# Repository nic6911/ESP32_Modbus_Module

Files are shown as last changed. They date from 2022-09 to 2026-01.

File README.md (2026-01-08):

# ESP32 Modbus Module

## Overview

The ESP32 Modbus module is designed for integrating Modbus-enabled devices with Home Assistant. It supports various devices including:

- **Nilan Ventilation** (CTS602/602Light and CTS400 with Modbus)
- **Wavin AHC9000** (Floor heating)
- **Wavin Sentio** (Floor heating)
- **EM340** (Electricity meter with Modbus)
- **NIBE F1255** (Heatpump)

The module is flexible and can be adapted for other Modbus applications, although no promises are made for unsupported devices.

[Buy the module here](https://www.ustepper.com/shop/#!/products/esphome-modbus-module)

---

## Disclaimer

**Use at your own risk!** Improper connections could potentially damage hardware. The hardware and software have been tested with the listed devices without issues.

---

## Features

- Modbus communication with popular home automation systems (e.g., **Home Assistant**, **ESPHome**).
- Supports multiple devices (Nilan, Wavin, EM340, NIBE, and more).
- Provides wiring and software guides to get started quickly.

---

## December 2025 - Hardware update !
Please be advised that the hardware have been updated with the major changes that the 2 x optocoupler outputs have been removed (legacy functionality), the 2 x pin rows are gone and the flow-control pin has been rewired to GPIO3. Nothing that impacts or degrades performance !

For the adapted code (adjusted flow-control pin) look here: [rev2](esphome_example_code/rev2)

If you have a rev2 - it'll look like this:

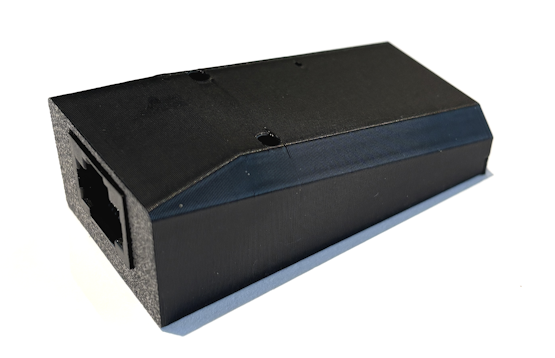
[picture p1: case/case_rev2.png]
Case


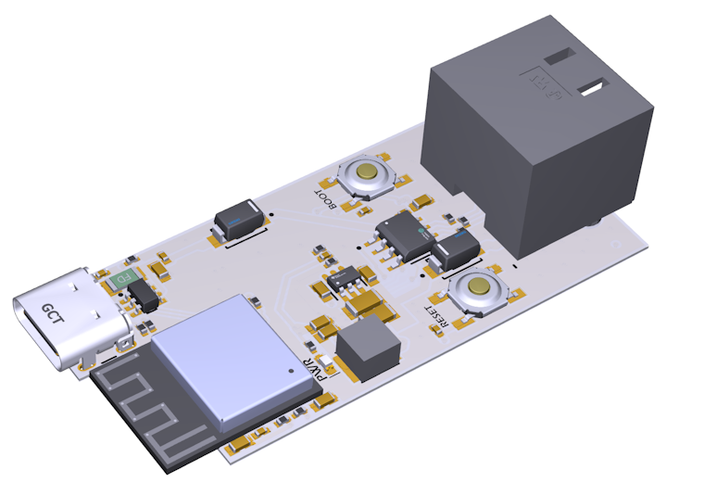
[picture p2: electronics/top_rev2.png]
Topview


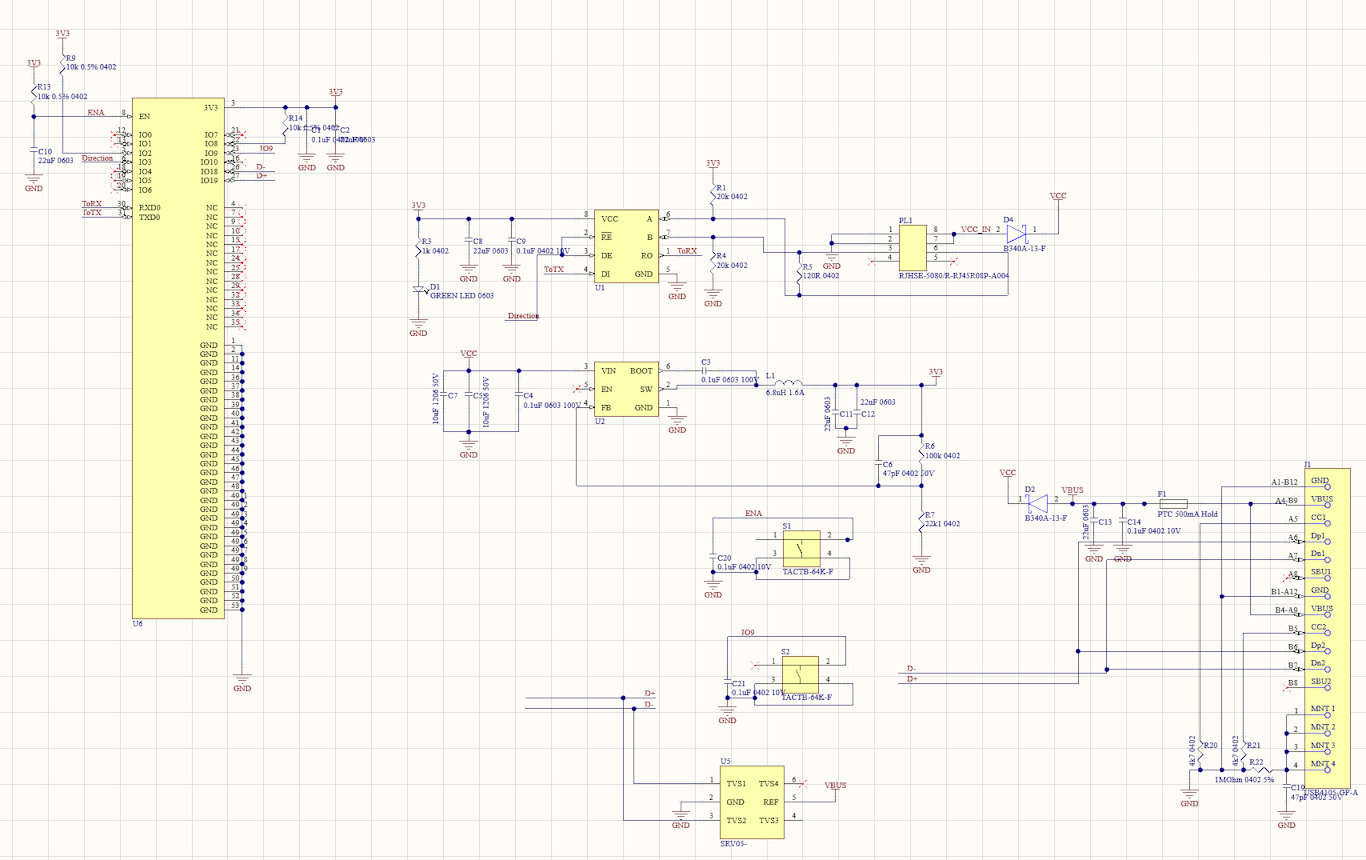
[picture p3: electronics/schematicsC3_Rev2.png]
Schematic


If you have a rev1 - it'll look like this:

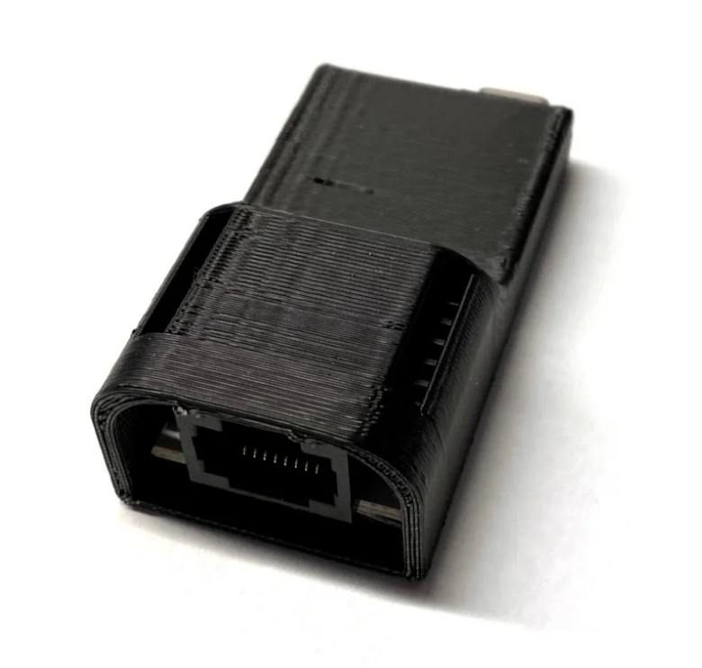
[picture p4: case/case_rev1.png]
Case


And the right code (GPIO10 flow-control pin) is here: [rev1](esphome_example_code/rev1)

## Connecting the Module

### Compatibility Notes

- **RJ45 Interface**: Works specifically with Wavin AHC9000/Sentio.
- Use a **patch cable** to connect the module to the Modbus port for these devices.

### Wiring Information

To connect the module, use an **RJ45B** cable. Cut the cable to expose colored wires, which serve the following functions:

- **A (Modbus+)**
- **B (Modbus-)**
- **GND**
- **+12V (optional)** for power, or use a **USB-C** cable from a charger.

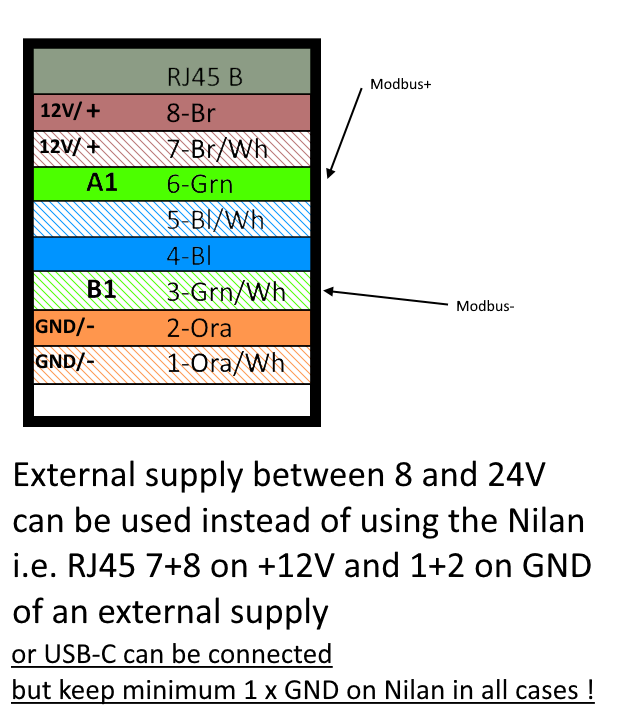
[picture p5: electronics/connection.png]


#### A wiring example on a Nilan CTS602 or CTS602 light is shown here:
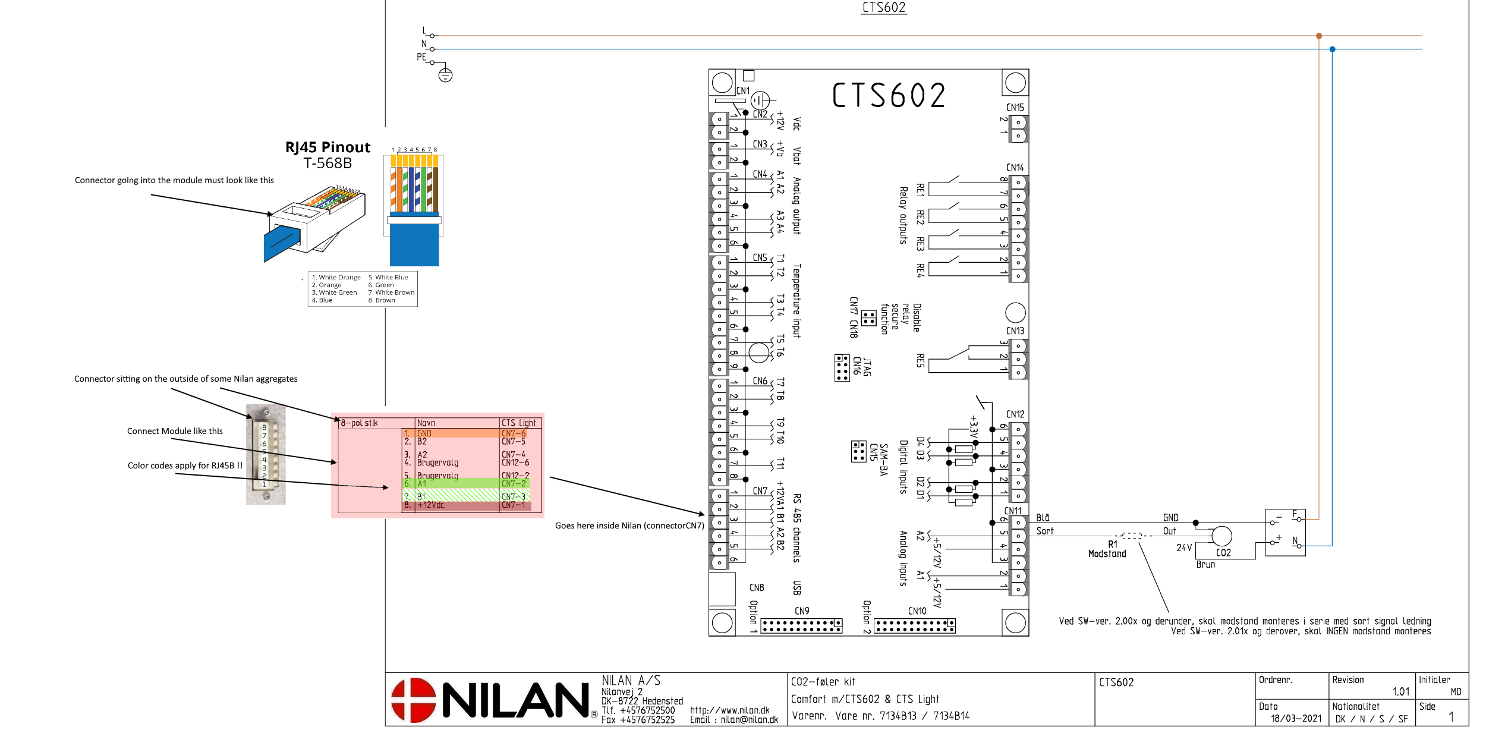
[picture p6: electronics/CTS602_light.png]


#### A wiring example on a Nilan CTS400 is shown here:
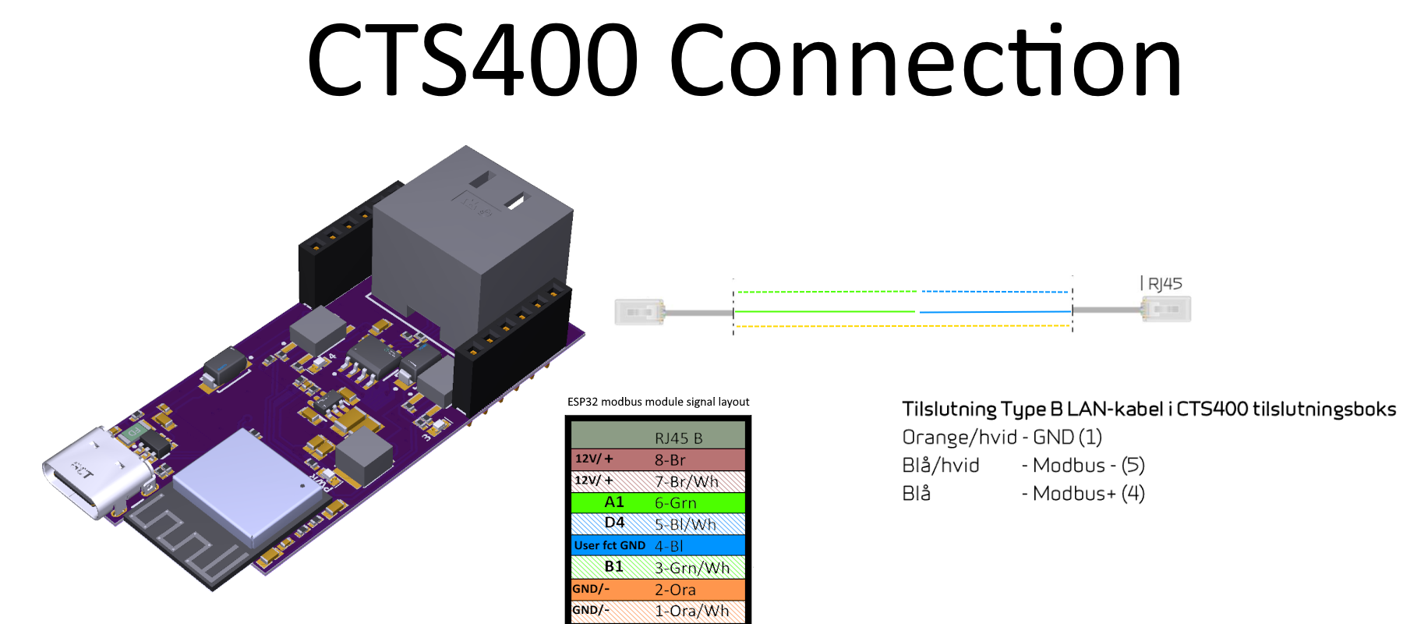
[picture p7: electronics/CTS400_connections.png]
Connections


#### A wiring example on a EM340 modbus power meter is shown here:
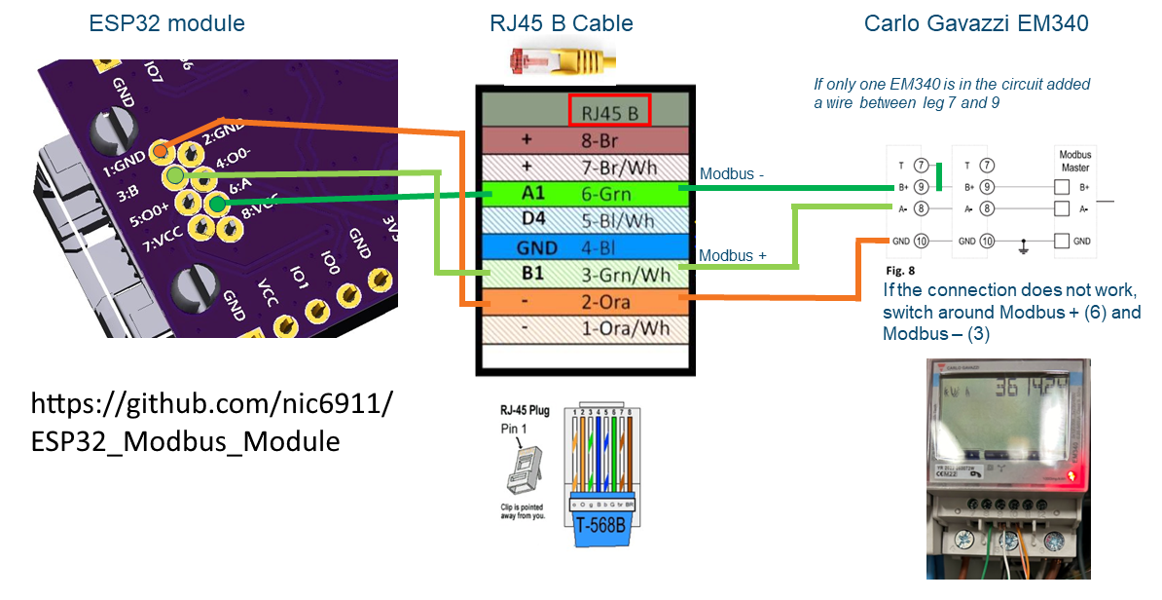
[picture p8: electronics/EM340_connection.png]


#### A Nibe Heat Pump modbus interface is shown here:
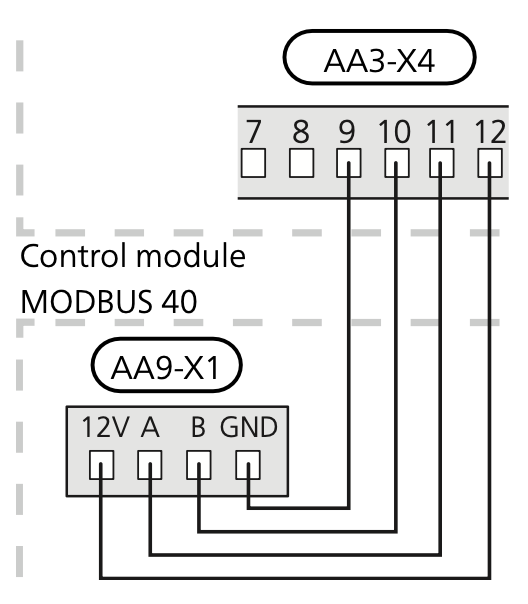
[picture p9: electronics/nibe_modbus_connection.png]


---

## Software Guides

### Installation & Setup

- **Home Assistant & ESPHome**: The module integrates seamlessly with these platforms.
- [Video Guide: USB + WiFi Upload for AHC9000](https://youtu.be/jKOnhiWMCx8)

### Example Code

You can find example code for **Nilan**, **Nibe**, **EM340**, and more in the code folder. A generic setup for **Nilan** is available [here](https://github.com/Jopand/esphome_components/blob/main/README.md).

Example configuration for **Nilan**:

```
esphome:
  name: nilan
esp32:
  board: esp32-c3-devkitm-1
  framework:
    type: arduino

wifi:
  ssid: !secret wifi_ssid
  password: !secret wifi_password
  output_power: "8.5"

uart:
  rx_pin: 20
  tx_pin: 21
  parity: EVEN
  baud_rate: 19200
  id: uart_modbus
  stop_bits: 1
  
modbus:
  id: modbus_id
  flow_control_pin: 10
  uart_id: uart_modbus

```

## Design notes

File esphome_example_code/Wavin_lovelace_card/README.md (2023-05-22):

# Wavin Lovelace Card
Add the .yaml code in a custom card in your lovelace setup. I have a Wavin Sentio system and thus I also have humidity readings.
I have made an automation that syncs all temperatures across the house if I adjust the temperature in the "Sync Temperatur" box. If I want to edit the individual temperatures I simply click on the specific room/zone and the thermostat pops up for me to adjust.

The result with black theme you can see here:
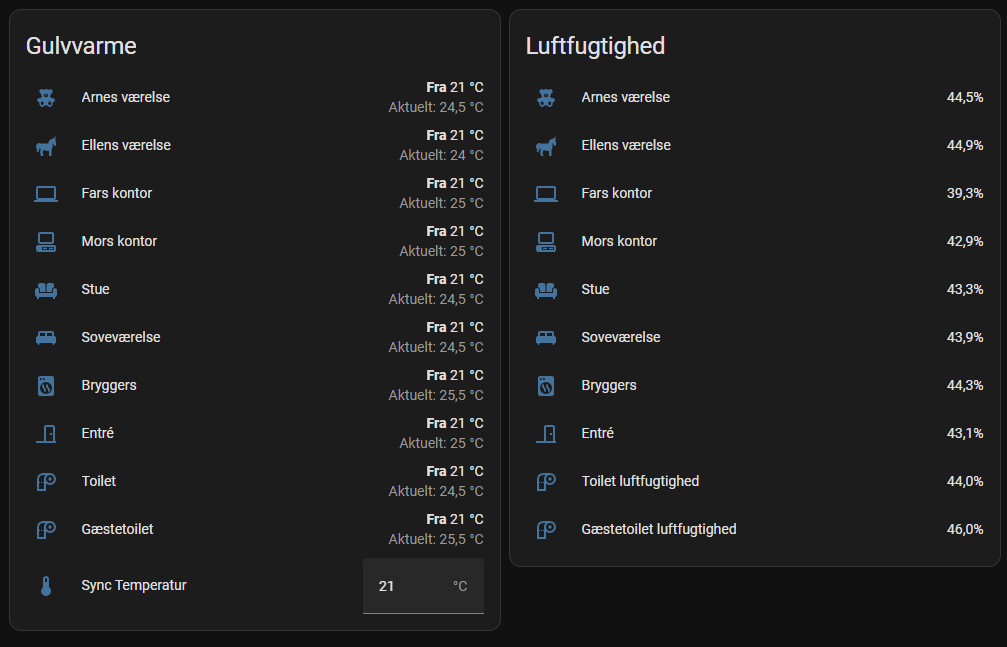
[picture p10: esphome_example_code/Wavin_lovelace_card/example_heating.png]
Example


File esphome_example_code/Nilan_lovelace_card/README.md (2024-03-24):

# Nilan Lovelace Card
Add the .yaml code in a custom card in your lovelace setup. The card has dependencies on HACS custom cards which you will see when trying to implement it. You must then get those dependencies through HACS. 
The `entilation_light.png` and `ventilation.png` image you will have to upload to your Home Assistant folder called "www". 

The result with black theme you can see here:
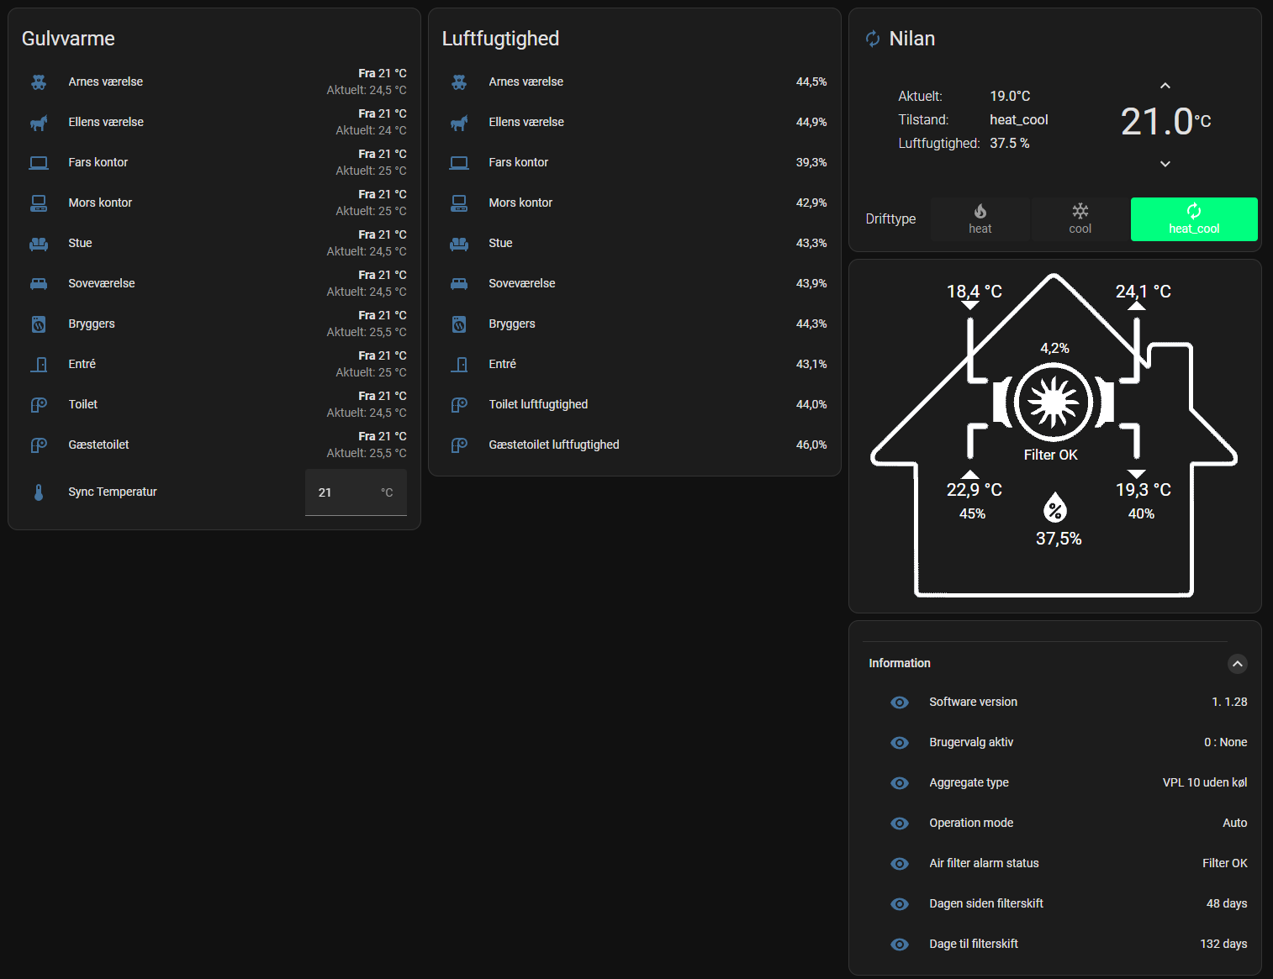
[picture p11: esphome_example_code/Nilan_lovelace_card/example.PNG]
Example


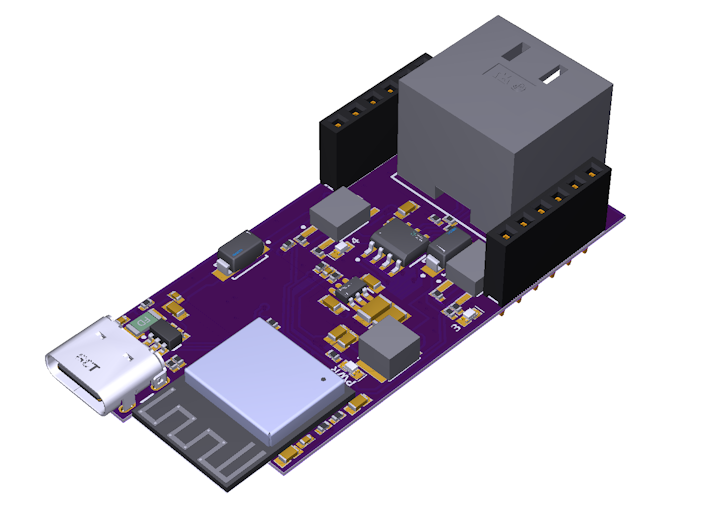
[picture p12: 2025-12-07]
electronics/top.png

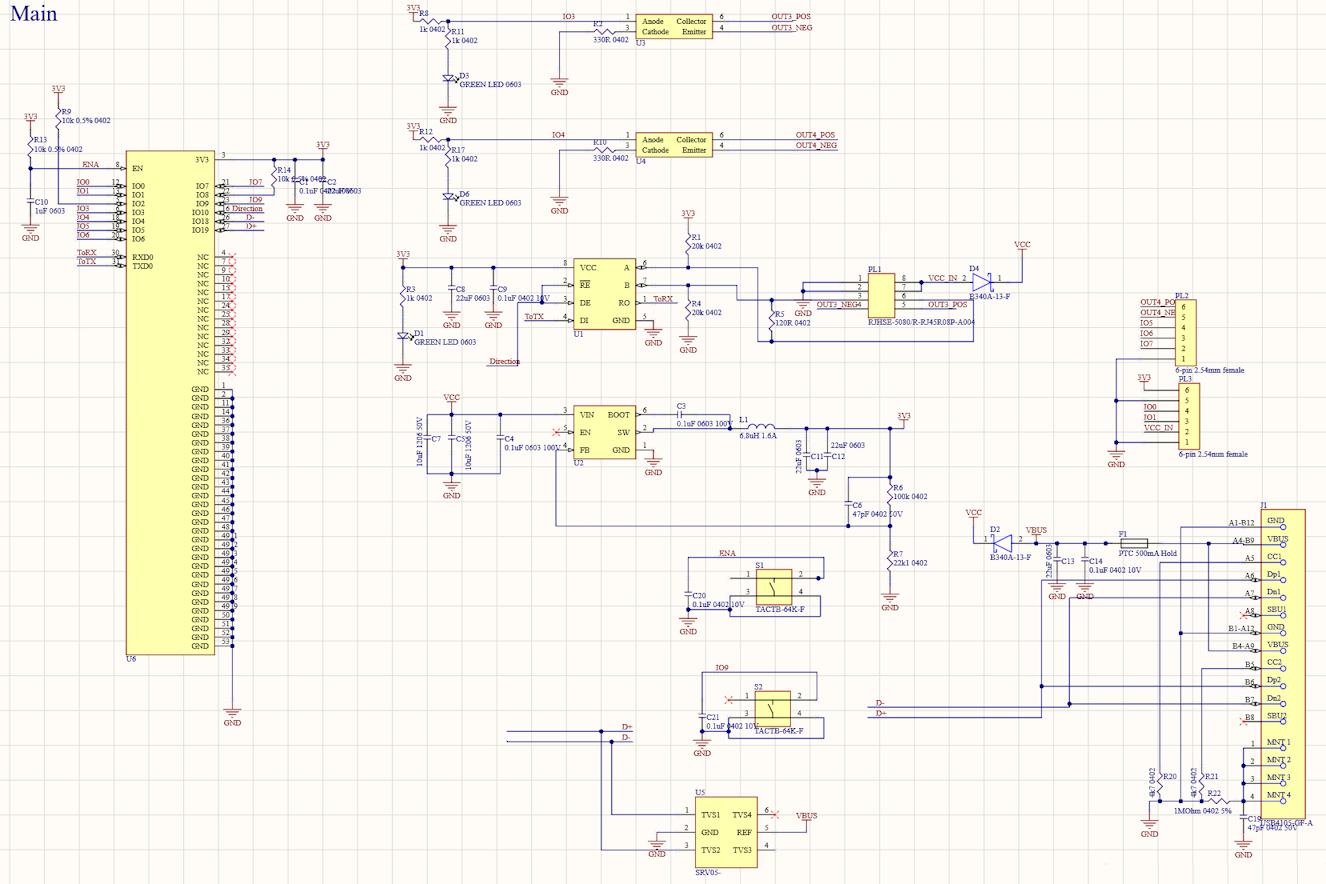
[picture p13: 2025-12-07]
electronics/schematicsC3.png

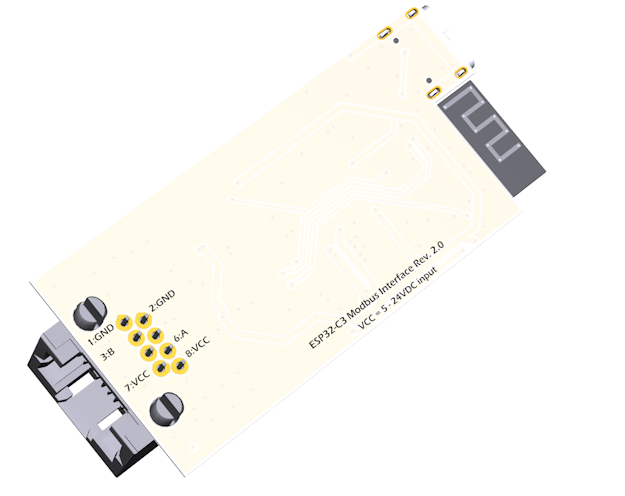
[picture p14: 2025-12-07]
electronics/bottom_rev2.png

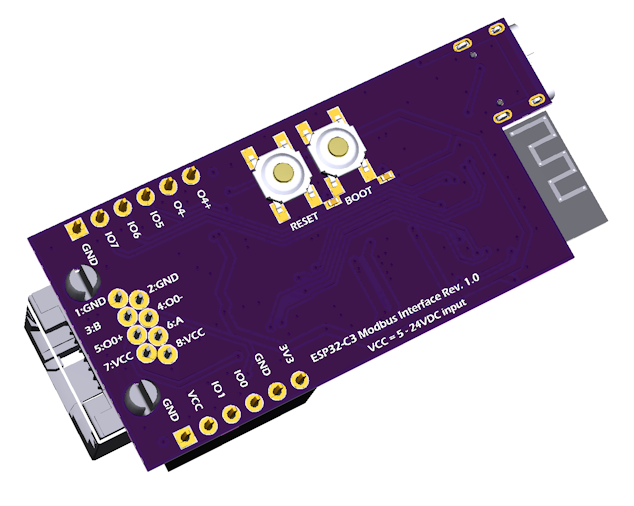
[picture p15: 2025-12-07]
electronics/bottom.png

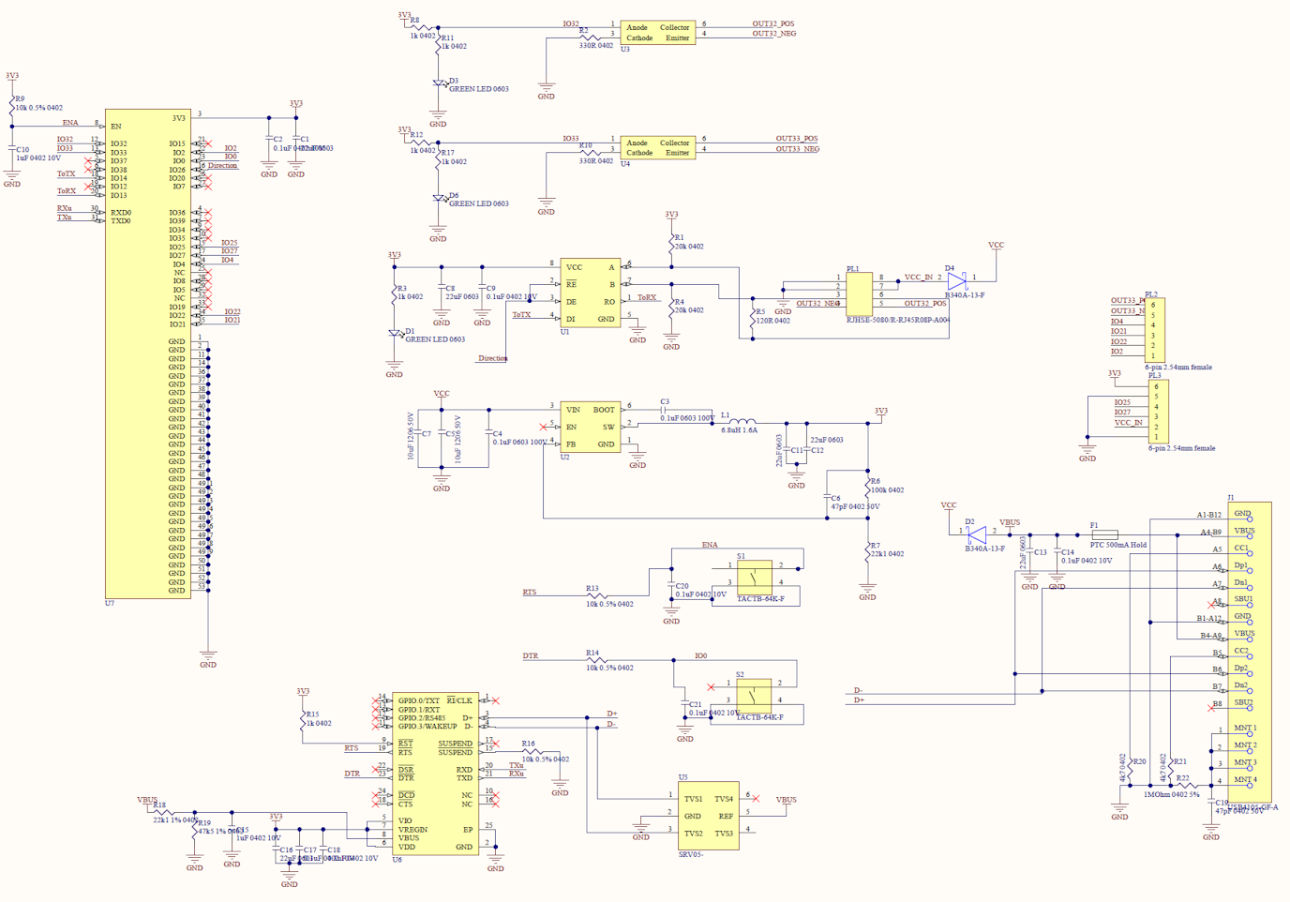
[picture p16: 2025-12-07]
electronics/schematics.png

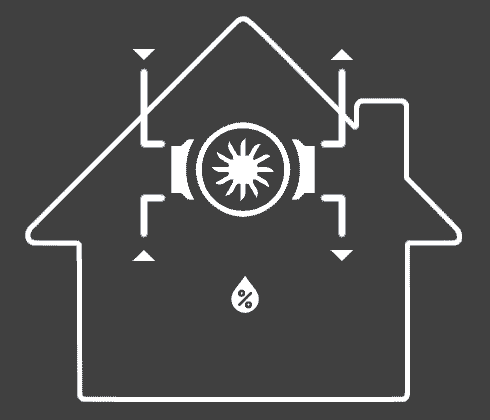
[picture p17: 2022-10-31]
esphome_example_code/Nilan_lovelace_card/ventilation.png

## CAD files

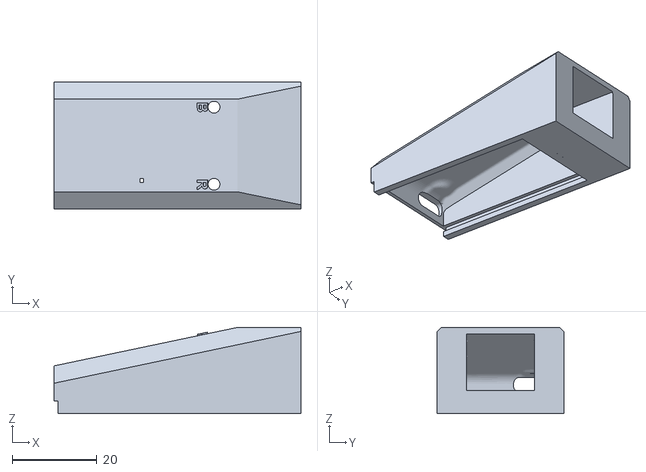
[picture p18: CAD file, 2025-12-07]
case/modbusWavinesp32_rev2_case.stl
58.2 x 29.9 x 20.3

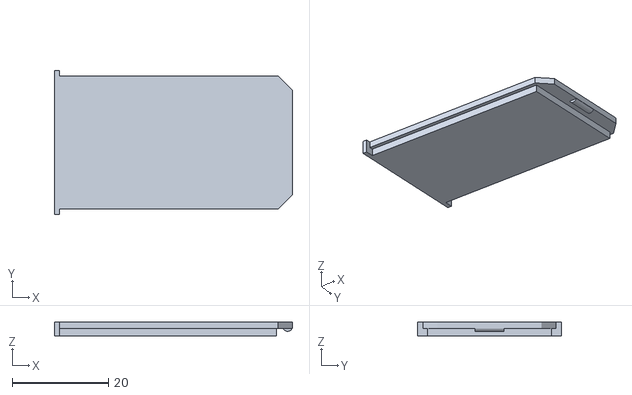
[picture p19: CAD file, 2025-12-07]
case/modbusWavinesp32_rev2_lid.stl
49.5 x 29.9 x 3.00

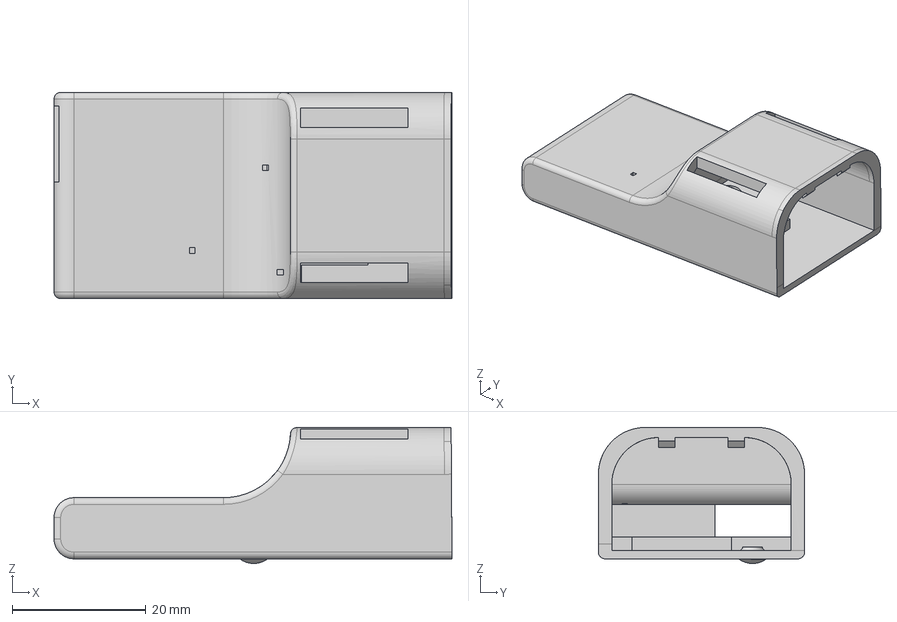
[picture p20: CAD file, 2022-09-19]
case/modbusWavinesp32.step
59.6 x 30.9 x 20.4 mm

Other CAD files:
case/modbusWavinesp32.stl

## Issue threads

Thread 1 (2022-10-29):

Combi 302 Polar missing

JunkStar2k, 2022-10-29:
name: "Aggregate type"
    id: nilan_platform_id
    register_type: holding
    address: 1000

case 35: type_str = "Combi 302 Polar"; break;

nic6911, 2023-11-05:
added

Closed 2023-11-05.

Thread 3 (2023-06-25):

Linked Channels Wavin

joamla96, 2023-06-25:
In my home I have 2 channels that are linked together on the adjuster in the house.

Short of hiding the secondary channel, and making automation that sync's the two, is there a way to combine them in the software as-is?

joamla96, 2023-06-25:
Okay, so, after playing around a little more with it, i may have been to quick to open an issue about it.

When I adjust the temperature on the module in the house, it only changes on one of the channels in Home Assistant, so I presume the head unit is handling the linked channel itself.

uStepper, 2023-07-05:
> Okay, so, after playing around a little more with it, i may have been to quick to open an issue about it.
>
> When I adjust the temperature on the module in the house, it only changes on one of the channels in Home Assistant, so I presume the head unit is handling the linked channel itself.

You are completely right - the head unit is handling this with combining two outputs and one thermostat. So, in case you have two combined channels you’ll just leave out one of them in the esphome code since it has no thermostat.

nic6911, 2023-07-05:
You are completely right - the head unit is handling this with combining two outputs and one thermostat. So, in case you have two combined channels you’ll just leave out one of them in the esphome code since it has no thermostat.

Closed 2023-07-05.

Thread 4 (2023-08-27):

No data

spasserkongen, 2023-08-27:
hvad gør jeg forkert?
jeg har et nilan 300LR, som umiddelbart har stik-forbindelse ligesom på dit readme-billede. Jeg har vedhæftet hvordan jeg har tilslutet ESP-32 modulet til anlægget. Jeg kører 12V udenom da det også drillede.

[logs_nilan_logs(4).txt](https://github.com/nic6911/ESP32_Modus_Module/files/12447694/logs_nilan_logs.4.txt)
![IMG_4053](https://github.com/nic6911/
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
ESP32_Modus_Module/assets/28684092/82012d03-78e1-49b8-861d-9e099c5d8527)

spasserkongen, 2023-08-27:
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

nic6911, 2023-08-27:
Ud fra billedet så har du enten sat orange til 12v (som modulet vil dø af) eller også sidder dine modbus ledninger et forkert sted hverfald hvis jeg kogger her: https://www.nilan.dk/Files/Files/Dansk/Downloads/3.%20Montagevejledninger/M24_Comfort-300LR_DK.pdfBest regards, MogensDen 27. aug. 2023 kl. 11.38 skrev spasserkongen ***@***.***>:

—Reply to this email directly, view it on GitHub, or unsubscribe.You are receiving this because you are subscribed to this thread.Message ID: ***@***.***>

Closed 2023-08-27.

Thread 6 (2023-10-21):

Change filter Alarm

nagydavid, 2023-10-21:
Hi Nico,

I have purchased, from you the ESP32-PICO version. I am using with the Nilan Comfort 300LR and CTS600. Everything is ok, but on the Alarm list in the CTS I am getting and ALARM 91, which is
|  91  |   I OPT IO          | Optionsprint mangler   | Kontakt service   |

and I cannot clear it.

when I press reset alarms, that does nothing. :(

Maybe you have some suggestion?

p.s.: I just would like to you the set/reset filter alarm

nic6911, 2023-11-05:
Have you tried the code from the ESP32-C3? There are some changes there. You of course need to adjust the start of the code to match the PICO instead. Else I would suggest trying out the restructured code from Jopand: https://github.com/Jopand/esphome_components/tree/main

Closed 2023-11-05.

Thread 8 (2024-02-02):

Request for help with wiring

Fredy72, 2024-02-02:
Here it is written about connecting the power supply directly from the CTS602, where, among other things, +12V and GND are output.
> https://github.com/nic6911/ESP32_Modbus_Module/raw/main/electronics/connection.png

Here is a picture of the LILYGO® T-CAN485 wiring in the Nibe heat pump, where PIN9 = GND and PIN12 = +12V (PINs 10 and 11 are Modbus).
> https://github.com/elupus/esphome-nibe/blob/master/examples/lilygo-t-can485.png

I own a LILYGO® T-CAN485 and would like to wiring it up to the CTS602 and powered directly from the CTS602 to the PINs 1,2,3,6.
Pin1 = 12 VDC output
Pin2 = COM1 - RS 485 Data+ (A) - Modbus
Pin3 = COM1 - RS 485 Data- (B) - Modbus
Pin6 = GND

The electrical diagram of the Lily device is as follows.
> https://github.com/Xinyuan-LilyGO/T-CAN485/blob/main/doc/schematic.pdf

I want to ask if it is possible to use the connection in Nilan as pictured with Nibe, i.e. the GND on the RS485 connector (middle PIN) would not be connected (it is written in the first link: "_but keep minimum 1x GND on Nilan in all cases!_")?
Thank you for your answer.

nic6911, 2024-02-02:
Hi,

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

page 4 in the Nilan modbus manual:
https://www.nilan.dk/Files/Files/Dansk/Downloads/7.%20Modbus%20-%20BACnet/2021-01-Modbus_CTS602_w_HMI350T_Modbus.pdf

Fredy72, 2024-02-02:
Thank you for your response.
So are any of these options correct?
In the picture at Nibe it is like this:
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
As an alternative, I thought of this:
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

Fredy72, 2024-02-02:
Another way would be to use the USB output from the CTS602 board to USB LilyGo to power the LilyGo. Would it work?

nic6911, 2024-02-05:
I don't know if the CTS602 has the USB power (or can power back through USB at all) to support that board you have there. With the wiring I can only refer to the doc from Nilan which states that you must use GND. If the GND and RS485GND on the board you have there are tied together I dont know... So the wiring would depend on that.

Closed 2024-02-02.

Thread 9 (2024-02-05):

AHC9000 example code - different versions and missing functionality.

victordk, 2024-02-05:
Hi

Back in 2022 or early 2023 there was a version 2 of the AHC9000 code that integrated more of heinekmadsens esp components.
It had binary sensors for heat output on the individual strings. The current example code does not have these binary sensors - and i am missing them for some automations.

Is there any chance we can have a working code example with those binary sensors?

Hope it makes sense.

nic6911, 2024-02-05:
I have added the V2 example here: esphome_example_code/WavinAHC9000V2_example.yaml

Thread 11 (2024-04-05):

Incorrect data reported from Wavin AHC 9000 with the modbus module.

gudmmk, 2024-04-05:
I'm using your ESP32 Modbus Module that I recently purchased, I hooked it up to a Wavin AHC 9000 ventillation system after I had followed your guide on YouTube on flashing the module for the Wavin AHC 9000.  The module is working great, but there are some discrepancies in the data that's being reported from the ventillation system.

There are 6 channels configured in the Wavin unit.

01: Living Room
03: Master Bedroom
04: Entrance
05: Bedroom 1
06: Bedroom 2
07: Bathroom

The first three issues I encountered are the following:

- Channel 07 reports the temperature as 0 °C. (The thermostat shows the correct temp for the room that it is in)
- Channel 06 is reporting the current temperature for Channel 07. (The thermostat shows the correct temp for the room that it is in)
- Channel 07 reports 0% as the thermostat battery status.

I replaced the batteries in the thermostat for Channel 07 and then I noticed that the battery status for the Channel 07 thermostat is reported as the battery status for the Channel 04 thermostat.

I'm a bit baffled by this, I'm not sure if this might be an issue with the way I did setup/configure the module or if this might be something in the Wavin unit itself.

Any thoughts on this?

[ESPHome_wavin.log](https://github.com/nic6911/ESP32_Modbus_Module/files/14889213/ESPHome_wavin.log)

Here's the YAML that I used to build the firmware and flash the modbus module with.

```
########################################################################################
#                                                                                      #
#      WAVIN AHC-9000 FLOOR HEATING CONTROLLER SOFTWARE FOR HOME ASSISTANT             #
#                                                                                      #
#        Code developed by : Heine Koldbro Madsen and Samuel Sieb 2021                 #
#                                                                                      #
# https://github.com/heinekmadsen/esphome_components/tree/main/components/wavinAhc9000 #
#                                                                                      #
# Hardware by : Mogens Groth Nicolaisen https://github.com/nic6911/Wavin-AHC-9000-mqtt #
#                                                                                      #
########################################################################################

########################################################################################
#                      CONFIGURATION PART OF YOUR CHOICE :)                            #
########################################################################################

substitutions:
  # UNIQUE NAME FOR THE DEVICE
  device: wavin # Case sensitive!!!
  name: "Wavin AHC 9000"  # "Friendly name" - not case sensitive!!!

  # CHANNEL friendly names (If using spaces remember to add ")
  channel_01_friendly_name: "Living Room"
  channel_02_friendly_name: "Channel 02"
  channel_03_friendly_name: "Master Bedroom"
  channel_04_friendly_name: "Entrance"
  channel_05_friendly_name: "Bedroom 1"
  channel_06_friendly_name: "Bedroom 2"
  channel_07_friendly_name: "Bathroom"
  channel_08_friendly_name: "Channel 08"
  channel_09_friendly_name: "Channel 09"
  channel_10_friendly_name: "Channel 10"
  channel_11_friendly_name: "Channel 11"
  channel_12_friendly_name: "Channel 12"
  channel_13_friendly_name: "Channel 13"
  channel_14_friendly_name: "Channel 14"
  channel_15_friendly_name: "Channel 15"
  channel_16_friendly_name: "Channel 16"
  channel_17_friendly_name: "Channel 17"

  # CHANNEL ID´S (ONLY LOWER CASE LETTERS, NO SPACES) used for entity ids
  channel_01_id: channel_01
  channel_02_id: channel_02
  channel_03_id: channel_03
  channel_04_id: channel_04
  channel_05_id: channel_05
  channel_06_id: channel_06
  channel_07_id: channel_07
  channel_08_id: channel_08
  channel_09_id: channel_09
  channel_10_id: channel_10
  channel_11_id: channel_11
  channel_12_id: channel_12
  channel_13_id: channel_13
  channel_14_id: channel_14
  channel_15_id: channel_15
  channel_16_id: channel_16
  channel_17_id: channel_17

 # CHANNEL Alignments (ONLY change if you have offsets in channel vs temperature. Some have reported this if using multiple strings pr. room thermostat)
  channel_01_sensor: "0x00"
  channel_02_sensor: "0x01"
  channel_03_sensor: "0x02"
  channel_04_sensor: "0x03"
  channel_05_sensor: "0x04"
  channel_06_sensor: "0x05"
  channel_07_sensor: "0x06"
  channel_08_sensor: "0x07"
  channel_09_sensor: "0x08"
  channel_10_sensor: "0x09"
  channel_11_sensor: "0x0A"
  channel_12_sensor: "0x0B"
  channel_13_sensor: "0x0C"
  channel_14_sensor: "0x0D"
  channel_15_sensor: "0x0E"
  channel_16_sensor: "0x0F"
  channel_17_sensor: "0x14"

  channel_01: "0x00"
  channel_02: "0x01"
  channel_03: "0x02"
  channel_04: "0x03"
  channel_05: "0x04"
  channel_06: "0x05"
  channel_07: "0x06"
  channel_08: "0x07"
  channel_09: "0x08"
  channel_10: "0x09"
  channel_11: "0x0A"
  channel_12: "0x0B"
  channel_13: "0x0C"
  channel_14: "0x0D"
  channel_15: "0x0E"
  channel_16: "0x0F"
  channel_17: "0x14"

   # UPDATE TIME (GATEWAY)
  update_interval: 60s

  # PIN DEFINITIONS (Should in most cases not be changed)
  rx_pin: '20'
  tx_pin: '21'

  # WiFi settings
  ssid_set: "<redacted>"
  password_set: "<redacted>"

########################################################################################
#                        CODE BELOW SHOULD NOT BE CHANGED                              #
########################################################################################

esphome:
  name: ${device}

esp32:
  board: esp32-c3-devkitm-1
  framework:
    type: arduino

# Enable logging
logger:
  baud_rate: 0

# Enable Home Assistant API
api:

ota:

wifi:
  ssid: ${ssid_set}
  password: ${password_set}

  # Enable fallback hotspot (captive portal) in case wifi connection fails
  ap:
    ssid: "Wavin Fallback Hotspot"
    password: "<redacted>"

captive_portal:

uart:
  - id: uart_${device}
    rx_pin: ${rx_pin}
    tx_pin: ${tx_pin}
    baud_rate: 38400
    stop_bits: 1
    parity: NONE

modbus:
    - id: ${device}_modbus
      uart_id: uart_${device}
      flow_control_pin: 10

modbus_controller:
  id: ${device}_modbus_controller
  address: 1
  modbus_id: wavin_modbus
  update_interval: ${update_interval}

packages:
  remote_package:
    url: https://github.com/nic6911/esphome_components
    ref: more_channels
    files:
      - components/wavinahc9000v2/configs/basic.yaml # REQUIRED FOR WAVIN AHC 9000
      - components/wavinahc9000v2/configs/channel_01.yaml
      #- components/wavinahc9000v2/configs/channel_01_comfort.yaml # Only for channels with thermostat with IR sensor
      - components/wavinahc9000v2/configs/channel_02.yaml
      #- components/wavinahc9000v2/configs/channel_02_comfort.yaml # Only for channels with thermostat with IR sensor
      - components/wavinahc9000v2/configs/channel_03.yaml
      #- components/wavinahc9000v2/configs/channel_03_comfort.yaml # Only for channels with thermostat with IR sensor
      - components/wavinahc9000v2/configs/channel_04.yaml
      #- components/wavinahc9000v2/configs/channel_04_comfort.yaml # Only for channels with thermostat with IR sensor
      - components/wavinahc9000v2/configs/channel_05.yaml
      #- components/wavinahc9000v2/configs/channel_05_comfort.yaml # Only for channels with thermostat with IR sensor
      - components/wavinahc9000v2/configs/channel_06.yaml
      #- components/wavinahc9000v2/configs/channel_06_comfort.yaml # Only for channels with thermostat with IR sensor
      - components/wavinahc9000v2/configs/channel_07.yaml
      #- components/wavinahc9000v2/configs/channel_07_comfort.yaml # Only for channels with thermostat with IR sensor
      - components/wavinahc9000v2/configs/channel_08.yaml
      #- components/wavinahc9000v2/configs/channel_08_comfort.yaml # Only for channels with thermostat with IR sensor
      - components/wavinahc9000v2/configs/channel_09.yaml
      #- components/wavinahc9000v2/configs/channel_09_comfort.yaml # Only for channels with thermostat with IR sensor
      - components/wavinahc9000v2/configs/channel_10.yaml
      #- components/wavinahc9000v2/configs/channel_10_comfort.yaml # Only for channels with thermostat with IR sensor
      - components/wavinahc9000v2/configs/channel_11.yaml
      #- components/wavinahc9000v2/configs/channel_11_comfort.yaml # Only for channels with thermostat with IR sensor
      - components/wavinahc9000v2/configs/channel_12.yaml
      #- components/wavinahc9000v2/configs/channel_12_comfort.yaml # Only for channels with thermostat with IR sensor
      - components/wavinahc9000v2/configs/channel_13.yaml
      #- components/wavinahc9000v2/configs/channel_13_comfort.yaml # Only for channels with thermostat with IR sensor
      - components/wavinahc9000v2/configs/channel_14.yaml
      #- components/wavinahc9000v2/configs/channel_14_comfort.yaml # Only for channels with thermostat with IR sensor
      - components/wavinahc9000v2/configs/channel_15.yaml
      #- components/wavinahc9000v2/configs/channel_15_comfort.yaml # Only for channels with thermostat with IR sensor
      - components/wavinahc9000v2/configs/channel_16.yaml
      #- components/wavinahc9000v2/configs/channel_16_comfort.yaml # Only for channels with thermostat with IR sensor
      - components/wavinahc9000v2/configs/channel_17.yaml
    refresh: 0s
```

nic6911, 2024-04-05:
Hi,

you have most likely two strings on one thermostat - which requires you to edit the offset section so that it does not try to read the channel thermostat that is not there.
 Read more here: https://github.com/heinekmadsen/esphome_components

Closed 2024-04-05.

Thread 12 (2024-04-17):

Couldn't find ID 'wavin_modbus'.

Inrego, 2024-04-17:
I'm trying to install on the unit I purchased. I'm using the yaml from https://github.com/nic6911/ESP32_Modbus_Module/blob/main/esphome_example_code/WavinAHC9000V2_example.yaml but during compile, I get the error `Couldn't find ID 'wavin_modbus'.`

Inrego, 2024-04-17:
Found the bug:

Changed this line:
https://github.com/nic6911/ESP32_Modbus_Module/blob/20d9334d7542a3a562a640915ec5420a52b6e496/esphome_example_code/WavinAHC9000V2_example.yaml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

to this:
`modbus_id: ${device}_modbus`

Closed 2024-04-19.

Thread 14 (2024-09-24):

Wanting to connect to DVI Heat Pump

Inrego, 2024-09-24:
Hi there. I'm already using one of these for my Waving floor heating. It's great!
Now, I'm looking to smartify my heat pump, which is a DVI Heat Pump. They've sent me the modbus specifications.

The connector is a DB-9 port. Do you think it would be so simple, that I can just use a cable like this to connect your device to the serial port?
https://www.proshop.dk/Kabler-diverse/Datalogic-CAB-327-RS232-CABLE-CABL/2348820

Or would I have to cut it and join the individual wires to a specific mapping?

nic6911, 2024-09-24:
Hi,
That really depends on the layout of that cable and the DVI Heat Pump. You can see the layout of my RJ45 connector here on the repo :) It would be a strike of luck if it just matched 1:1 with Wavin I guess...

Inrego, 2024-09-24:
I'm just thinking, that since these kinds of cables do exist, there's probably some standardized mapping between the two connectors. So it might not just be luck. But it sounds like you don't necessarily have any knowledge on the subject, so I'll research some more on my own.

nic6911, 2024-09-24:
Based on my knowledge on Nilan and Wavin (which both can have RJ45 connectors for modbus) I would not expect it to follow any standard. And no, I do not know exactly how that cable you refer to is pinned out and how the DVI unit has it's layout on the DB9 connector :) You'll have to do a little research there on your own :)

Inrego, 2024-09-30:
I found one of these bad boys. It's arriving today. So time to tinker!
https://www.av-cables.dk/d-sub-stik/terminal-block-adapter-sub-d-9-pin-han-til-til-terminal-block.html

Closed 2024-09-24.

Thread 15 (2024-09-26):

Wavin sentio ccu8 no data

tvc-dps, 2024-09-26:
Hello

Using module from https://www.ustepper.com/shop/#!/products/esphome-modbus-module
Physically connected over rj45 to Wavin Sentio CCU-208 port A (1st on the left)
Used template/configuration example at https://github.com/nic6911/ESP32_Modbus_Module/blob/main/esphome_example_code/WavinSentio_example.yaml

No data received.
Below is the log:

```
[10:58:39][D][api.connection:1445]: Home Assistant 2024.9.3 (192.168.100.79): Connected successfully
[10:58:39][C][modbus_controller.sensor:010]: modbus_controller.sensorModbus Controller Sensor 'Living room dugpunkt'
[10:58:39][C][modbus_controller.sensor:010]: modbus_controller.sensor  Device Class: 'humidity'
[10:58:39][C][modbus_controller.sensor:010]: modbus_controller.sensor  State Class: ''
[10:58:39][C][modbus_controller.binary_sensor:009]: Modbus Controller Binary Sensor 'Lav batteri Living room'
[10:58:39][C][sentio.climate:055]: Sentio Climate 'Bathroom LVL2'
[10:58:39][C][sentio.climate:055]: Sentio Climate 'Bathroom LVL1'
[10:58:39][C][sentio.climate:055]: Sentio Climate 'Kitchen'
[10:58:39][C][sentio.climate:055]: Sentio Climate 'Hallway'
[10:58:39][C][sentio.climate:055]: Sentio Climate 'Living room'
[10:58:39][C][modbus_controller:345]: ModbusController:
[10:58:39][C][modbus_controller:346]:   Address: 0x01
[10:58:39][C][modbus_controller:347]:   Max Command Retries: 4
[10:58:39][C][captive_portal:089]: Captive Portal:
[10:58:40][D][modbus_controller:038]: Modbus command to device=1 register=0x78 no response received - removed from send queue
[10:58:40][W][modbus:114]: Modbus CRC Check failed! 71A1!=A2FD
[10:58:40][W][modbus:114]: Modbus CRC Check failed! 7108!=FDA2
[10:58:40][W][modbus:114]: Modbus CRC Check failed! 98B0!=A4FC
[10:58:40][W][modbus:114]: Modbus CRC Check failed! 115A!=FCA4
[10:58:40][W][modbus:114]: Modbus CRC Check failed! 4040!=FFFF
[10:58:40][W][modbus:114]: Modbus CRC Check failed! 4040!=FFA2
[10:58:40][W][modbus:114]: Modbus CRC Check failed! ABB1!=A0FF
[10:58:41][W][modbus:114]: Modbus CRC Check failed! 71A1!=A2FD
[10:58:41][W][modbus:114]: Modbus CRC Check failed! 7108!=FDA2
[10:58:41][D][modbus_controller:038]: Modbus command to device=1 register=0x7A no response received - removed from send queue
[10:58:41][W][modbus:114]: Modbus CRC Check failed! 98B0!=EBFC
[10:58:41][W][modbus:114]: Modbus CRC Check failed! 6331!=FFFF
[10:58:41][W][modbus:114]: Modbus CRC Check failed! 4040!=FFFF
[10:58:41][W][modbus:114]: Modbus CRC Check failed! AA91!=A2FF
[10:58:41][W][modbus:114]: Modbus CRC Check failed! B079!=FFA6
[10:58:42][W][modbus:114]: Modbus CRC Check failed! 71A1!=A2FD
[10:58:42][W][modbus:114]: Modbus CRC Check failed! 7108!=FDA2
[10:58:42][W][modbus:114]: Modbus CRC Check failed! 98B0!=A4FC
[10:58:42][W][modbus:114]: Modbus CRC Check failed! 115A!=FCA4
[10:58:42][W][modbus_controller:182]: Duplicate modbus command found: type=0x3 address=219 count=1
[10:58:42][W][modbus_controller:182]: Duplicate modbus command found: type=0x3 address=220 count=1
[10:58:42][W][modbus_controller:182]: Duplicate modbus command found: type=0x3 address=222 count=1
[10:58:42][W][modbus_controller:182]: Duplicate modbus command found: type=0x3 address=319 count=1
[10:58:42][W][modbus_controller:182]: Duplicate modbus command found: type=0x3 address=320 count=1
[10:58:42][W][modbus_controller:182]: Duplicate modbus command found: type=0x3 address=322 count=1
[10:58:42][W][modbus_controller:182]: Duplicate modbus command found: type=0x3 address=419 count=1
[10:58:42][W][modbus_controller:182]: Duplicate modbus command found: type=0x3 address=420 count=1
[10:58:42][W][modbus_controller:182]: Duplicate modbus command found: type=0x3 address=422 count=1
[10:58:42][W][modbus_controller:182]: Duplicate modbus command found: type=0x3 address=819 count=1
[10:58:42][W][modbus_controller:182]: Duplicate modbus command found: type=0x3 address=820 count=1
[10:58:42][W][modbus_controller:182]: Duplicate modbus command found: type=0x3 address=822 count=1
[10:58:42][W][modbus_controller:182]: Duplicate modbus command found: type=0x4 address=101 count=4
[10:58:42][W][modbus_controller:182]: Duplicate modbus command found: type=0x4 address=106 count=2
[10:58:42][W][modbus_controller:182]: Duplicate modbus command found: type=0x4 address=201 count=4
[10:58:42][W][modbus_controller:182]: Duplicate modbus command found: type=0x4 address=206 count=2
[10:58:42][W][modbus_controller:182]: Duplicate modbus command found: type=0x4 address=301 count=4
[10:58:43][W][modbus:114]: Modbus CRC Check failed! 71A1!=A2FD
[10:58:43][W][modbus:114]: Modbus CRC Check failed! 7108!=FDA2
[10:58:43][W][modbus:114]: Modbus CRC Check failed! 98B0!=A4FC
[10:58:43][W][modbus:114]: Modbus CRC Check failed! 115A!=FCA4
[10:58:43][W][modbus:114]: Modbus CRC Check failed! 4040!=FFFF
[10:58:43][W][modbus:114]: Modbus CRC Check failed! 4040!=FFA2
[10:58:43][W][modbus:114]: Modbus CRC Check failed! ABB1!=A0FF
[10:58:43][W][modbus:114]: Modbus CRC Check failed! 107A!=DFFD
[10:58:44][D][modbus_controller:038]: Modbus command to device=1 register=0xDC no response received - removed from send queue
[10:58:44][W][modbus:114]: Modbus CRC Check failed! 71A1!=A2FD
[10:58:44][W][modbus:114]: Modbus CRC Check failed! 7108!=FDA2
[10:58:44][W][modbus:114]: Modbus CRC Check failed! 98B0!=A4FC
[10:58:44][W][modbus:114]: Modbus CRC Check failed! 115A!=FCA4`

```
Could you please help with possible troubleshooting directions?
Thank you

nic6911, 2024-09-26:
Hi - have you activated modbus on the Sentio unit (default is that it is disabled)? Do you have display on the unit at the same time as the modbus module?

tvc-dps, 2024-09-27:
I do not have a display to with a console connection. I have pc/laptop with a modem, but still have no idea how to check modbus activation.

nic6911, 2024-09-27:
https://github.com/nic6911/Wavin-Sentio/blob/main/documentation/Sentio_Modbus_170619_Print.pdf

tvc-dps, 2024-10-01:
I have no wavin display with console to check :sad_frog:
please close the issue

nic6911, 2024-10-02:
Personally I got Wavin to open modbus remotely by writing their support and having my Sentio online. I don’t know if that was an exception…

besides that it seems immensely stupid that modbus is disabled by default 🤦‍♂️

dlangeland, 2024-10-15:
I used this method to enable modbus on the Sentio myself without the display:
1. Connect LAN
2. Install mobile phone app and register the unit
3. Go to Settings -> Temporary access management
4. Install the SW from here: https://wavin.com/en-en/sentio-smartconnect
5. Create a user in the new SW (needs to use a different email address)
6. Add a remote connection using the S/N + credentials for the temporary access setup in the mobile app
7. Start the remote display connection
8. System -> Modbus Configuration
9. RTU mode -> Slave Read/Write
10. ...wait for reboot...
11. Again go to System -> Modbus Configuration
12. Change Parity to None and stop bits to 1 (compare with your esphome yaml settings)
13. Profit

Closed 2024-10-01.

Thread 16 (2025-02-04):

Failed to perform action + slow response time

andrzejom, 2025-02-04:
Hey, I'm writing in connection to a "potential" issue with the integration. I'm running everything with docker (Homeassistant + ESPhome + MQTT). I have bought [ESP32](https://www.ustepper.com/shop/#!/products/esphome-modbus-module). I have installed the config (1st version) from this repository. By default update interval was set to 60s. Later on from ESPhome, I changed it to 10 (and saved it). After validating the config logs (attached below) show a 10s interval. Not sure if I have to reinstall the module after such a configuration change. Response from integration (based on logs) are quite long 30s+ and they vary. Sometimes it is 30s sometimes it is almost 60s. Not sure where this issue is coming from.

In addition to the above HA reports sometimes an error message that states "Failed to perform the action climate/set_hvac_mode. Expected [...]" as seen on the screenshot attached as well. While reading accessible forums/issues I haven't seen the "problems" that I'm trying to describe here. Looking forward to your answers!

In general, it is a wonderful job both with the module and also with code integration. So huge thanks to the authors and contributors in this project, you are doing an awesome job!

[logs_wavin_logs - redacted.txt](https://github.com/user-attachments/files/18662621/logs_wavin_logs.-.redacted.txt)
[logs_wavin_validate.txt](https://github.com/user-attachments/files/18662620/logs_wavin_validate.txt)

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

nic6911, 2025-02-04:
Hi,

Don’t exactly see how you get this HVAC mode error unless you try to set the mode?
Haven’t seen it before.

Do you have a display sitting on your AHC9000?

andrzejom, 2025-02-05:
Hey, thanks for the reply, no i don't have a display connected to the relay

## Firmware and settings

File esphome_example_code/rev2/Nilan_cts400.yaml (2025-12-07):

esphome:
  name: nilan
esp32:
  board: esp32-c3-devkitm-1
  framework:
    type: arduino


# Enable logging
logger:
  baud_rate: 0

# Enable Home Assistant API
api:

ota:
  platform: esphome

wifi:
  ssid: !secret wifi_ssid
  password: !secret wifi_password

  # Enable fallback hotspot (captive portal) in case wifi connection fails
  ap:
    ssid: "Nilan Fallback Hotspot"
    password: ""

captive_portal:

uart:
  rx_pin: 20
  tx_pin: 21
  parity: EVEN
  baud_rate: 19200
  id: uart_modbus
  stop_bits: 1
  
modbus:
  id: modbus_id
  flow_control_pin: 3
  uart_id: uart_modbus
  
modbus_controller:
  id: nilan_modbus_controller
  address: 30
  modbus_id: modbus_id
  update_interval: 10s
 
external_components:
  - source: github://Jopand/esphome_components
    refresh: 0s
    
nilan:
    
select:
      
  - platform: modbus_controller
    modbus_controller_id: nilan_modbus_controller
    name: "Set operation mode"
    id: nilan_set_operation_mode
    address: 70
    value_type: U_WORD
    optionsmap:
      "Off" : 0
      "Auto" : 1


sensor:

#########################
#### INPUT REGISTERS ####
#########################

  - platform: modbus_controller
    modbus_controller_id: nilan_modbus_controller
    name: "Outlet temperature"
    id: nilan_outlet_temp_t4
    unit_of_measurement: °C
    accuracy_decimals: 1
    device_class: temperature
    register_type: read
    value_type: S_WORD
    address: 30
    filters:
      - multiply: 0.1
      
  - platform: modbus_controller
    modbus_controller_id: nilan_modbus_controller
    name: "Inlet temperature"
    id: nilan_inlet_temp_t2
    unit_of_measurement: °C
    accuracy_decimals: 1
    register_type: read
    value_type: S_WORD
    address: 28
    filters:
      - multiply: 0.1

  - platform: modbus_controller
    modbus_controller_id: nilan_modbus_controller
    name: "Outdoor temperature"
    id: nilan_outdoor_temp_t1
    unit_of_measurement: °C
    accuracy_decimals: 1
    device_class: temperature
    register_type: read
    value_type: S_WORD
    address: 27
    filters:
      - multiply: 0.1
      
  - platform: modbus_controller
    modbus_controller_id: nilan_modbus_controller
    name: "Exhaust temperature"
    id: nilan_exhaust_temp_t3
    unit_of_measurement: °C
    accuracy_decimals: 1
    device_class: temperature
    register_type: read
    value_type: S_WORD
    address: 29
    filters:
      - multiply: 0.1
      
  - platform: modbus_controller
    modbus_controller_id: nilan_modbus_controller
    name: "Humidity"
    id: nilan_humidity
    unit_of_measurement: '%'
    accuracy_decimals: 1
    device_class: humidity
    register_type: read
    address: 31
    filters:
      - multiply: 0.1

  - platform: modbus_controller
    modbus_controller_id: nilan_modbus_controller
    name: "Active alarms"
    id: nilan_active_alarms
    accuracy_decimals: 0
    register_type: read
    address: 50

  - platform: modbus_controller
    modbus_controller_id: nilan_modbus_controller
    name: "Alarm list 1 id"
    id: nilan_alarm_list_1_id
    accuracy_decimals: 0
    register_type: read
    address: 51

  - platform: modbus_controller
    modbus_controller_id: nilan_modbus_controller
    name: "Alarm list 1 info"
    id: nilan_alarm_list_1_info
    accuracy_decimals: 0
    register_type: read
    address: 56
    
  - platform: modbus_controller
    modbus_controller_id: nilan_modbus_controller
    name: "Alarm list 2 id"
    id: nilan_alarm_list_2_id
    accuracy_decimals: 0
    register_type: read
    address: 52

  - platform: modbus_controller
    modbus_controller_id: nilan_modbus_controller
    name: "Alarm list 2 info"
    id: nilan_alarm_list_2_info
    accuracy_decimals: 0
    register_type: read
    address: 57

  - platform: modbus_controller
    modbus_controller_id: nilan_modbus_controller
    name: "Alarm list 3 id"
    id: nilan_alarm_list_3_id
    accuracy_decimals: 0
    register_type: read
    address: 53

  - platform: modbus_controller
    modbus_controller_id: nilan_modbus_controller
    name: "Alarm list 3 info"
    id: nilan_alarm_list_3_info
    accuracy_decimals: 0
    register_type: read
    address: 58
    
  - platform: modbus_controller
    modbus_controller_id: nilan_modbus_controller
    name: "Actual fan step"
    id: nilan_actual_fan_step
    accuracy_decimals: 0
    register_type: read
    address: 63               

  - platform: modbus_controller
    modbus_controller_id: nilan_modbus_controller
    name: "Days to next filter change"
    id: nilan_days_to_next_filter_alarm
    unit_of_measurement: 'days'
    accuracy_decimals: 0
    register_type: read
    address: 110
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

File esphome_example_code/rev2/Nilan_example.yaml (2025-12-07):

esphome:
  name: nilan
esp32:
  board: esp32-c3-devkitm-1
  framework:
    type: arduino


# Enable logging
logger:
  baud_rate: 0
  
# Enable Home Assistant API
api:

ota:
  platform: esphome

wifi:
  ssid: !secret wifi_ssid
  password: !secret wifi_password

  # Enable fallback hotspot (captive portal) in case wifi connection fails
  ap:
    ssid: "Nilan Fallback Hotspot"
    password: ""

captive_portal:
  
uart:
  rx_pin: 20
  tx_pin: 21
  parity: EVEN
  baud_rate: 19200
  id: uart_modbus
  stop_bits: 1
  
modbus:
  id: modbus_id
  flow_control_pin: 3
  uart_id: uart_modbus
  
modbus_controller:
  id: nilan_modbus_controller
  address: 30
  modbus_id: modbus_id
  update_interval: 30s
 
external_components:
  - source: github://Jopand/esphome_components@main
    refresh: 0s
 
nilan:
    
select:
  - platform: modbus_controller
    modbus_controller_id: nilan_modbus_controller
    name: "Set user function"
    id: nilan_set_user_function
    address: 601
    force_new_range: true
    use_write_multiple: true
    value_type: U_WORD
    optionsmap:
      "None" : 0
      "Extend" : 1
      "Inlet" : 2
      "Exhaust" : 3
      "External heater offset" : 4
      "Ventilate" : 5
      "Cooker Hood" : 6

  - platform: modbus_controller
    modbus_controller_id: nilan_modbus_controller
    name: "Set user function 2"
    id: nilan_set_user_function2
    address: 611
    force_new_range: true
    use_write_multiple: true
    value_type: U_WORD
    optionsmap:
      "None" : 0
      "Extend" : 1
      "Inlet" : 2
      "Exhaust" : 3
      "External heater offset" : 4
      "Ventilate" : 5
      "Cooker Hood" : 6
      
  - platform: modbus_controller
    modbus_controller_id: nilan_modbus_controller
    name: "Set operation mode"
    id: nilan_set_operation_mode
    address: 1002
    force_new_range: true
    use_write_multiple: true
    value_type: U_WORD
    optionsmap:
      "Off" : 0
      "Heat" : 1
      "Cool" : 2
      "Auto" : 3


sensor:
  # WiFi signal sensor to ensure base sensor component is compiled
  - platform: wifi_signal
    name: "WiFi Signal"
    update_interval: 60s

#########################
#### INPUT REGISTERS ####
#########################

  - platform: modbus_controller
    modbus_controller_id: nilan_modbus_controller
    name: "Bus version"
    id: nilan_bus_version
    accuracy_decimals: 0
    register_type: read
    address: 0

  - platform: modbus_controller
    modbus_controller_id: nilan_modbus_controller
    name: "Exhaust temperature"
    id: nilan_exhaust_temp_t3
    unit_of_measurement: °C
    accuracy_decimals: 1
    device_class: temperature
    register_type: read
    value_type: S_WORD
    address: 203
    filters:
      - multiply: 0.01
      
  - platform: modbus_controller
    modbus_controller_id: nilan_modbus_controller
    name: "Outlet temperature"
    id: nilan_outlet_temp_t4
    unit_of_measurement: °C
    accuracy_decimals: 1
    device_class: temperature
    register_type: read
    value_type: S_WORD
    address: 204
    filters:
      - multiply: 0.01

  - platform: modbus_controller
    modbus_controller_id: nilan_modbus_controller
    name: "Inlet (after heater) temperature"
    id: nilan_inlet_temp_t7
    unit_of_measurement: °C
    accuracy_decimals: 1
    device_class: temperature
    register_type: read
    value_type: S_WORD
    address: 207
    filters:
      - multiply: 0.01

  - platform: modbus_controller
    modbus_controller_id: nilan_modbus_controller
    name: "Outdoor temperature"
    id: nilan_outdoor_temp_t8
    unit_of_measurement: °C
    accuracy_decimals: 1
    device_class: temperature
    register_type: read
    value_type: S_WORD
    address: 208
    filters:
      - multiply: 0.01

  - platform: modbus_controller
    modbus_controller_id: nilan_modbus_controller
    name: "Humidity"
    id: nilan_humidity
    unit_of_measurement: '%'
    accuracy_decimals: 1
    device_class: humidity
    register_type: read
    address: 221
    filters:
      - multiply: 0.01

  - platform: modbus_controller
    modbus_controller_id: nilan_modbus_controller
    name: "Active alarms"
    id: nilan_active_alarms
    accuracy_decimals: 0
    register_type: read
    address: 400

  - platform: modbus_controller
    modbus_controller_id: nilan_modbus_controller
    name: "Alarm list 1 id"
    id: nilan_alarm_list_1_id
    accuracy_decimals: 0
    register_type: read
    address: 401
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

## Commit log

2022-09-19 Added case source file and STL
    [modbusWavinesp32.step, modbusWavinesp32.stl]
2022-09-22 fixed setpoint write issue...
    [WavinSentio_example.yaml]
2022-10-10 stepfile of pcb added
2022-10-18 added a bunch of features
    holiday mode, holiday mode temperatures, keypad lock, battery low warning, and channel error
    [WavinSentio_example.yaml]
2022-11-06 schematic and description update for nilan
2022-12-01 copmax10 code
    for heat pump copmax10
2023-02-10 code support for ESP32C3
2023-02-13 added info for ESP32-C3
2023-03-06 CTS400 value type fix
    changed temp to signed word
    [Nilan_cts400.yaml]
2023-10-17 Heatpump lovelace card
2023-11-05 case 35: type_str = "Combi 302 Polar"; break;
2023-12-16 update em340 schematic
2024-04-19 Update WavinAHC9000V2_example.yaml
    minor bug with hardcoded value
    [WavinAHC9000V2_example.yaml]
2024-05-15 Fixed device classes for var and VA sensors
    [em340.yaml]
2025-10-26 Change flow control pin to TX enable pin
2025-11-12 Refactor Wavin AHC9000 configuration
    Updated friendly names and modified external component source. Changed update interval and adjusted sensor names to Danish.
2025-12-07 rev2 HW
    [modbusWavinesp32_rev2_case.stl, modbusWavinesp32_rev2_lid.stl]
2026-03-10 Update WavinAHC9000V3 examples to use nic6911 fork with RS485 timing fixes
    Point rev1 and rev2 example YAMLs at nic6911/esphome_components@feature/timingfixes
    which includes RS485 bus timing fixes that eliminate modbus communication timeouts.
    [WavinAHC9000V3_example.yaml]
2026-03-13 Update V3 example to reference upstream repo (heinekmadsen/esphome_components@main)
    The feature/timingfixes branch was merged to upstream via PR #75.
    Point the example at the canonical source so users get fixes directly.
    [WavinAHC9000V3_example.yaml]
2026-10-13 now with external sensor support example
